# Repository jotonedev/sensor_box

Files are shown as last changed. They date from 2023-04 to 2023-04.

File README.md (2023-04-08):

# Sensor box v1

Final result

## Objective

Create a system capable of collecting environmental data and sending it to an MQTT broker by connecting to WiFi.

## Data to collect

- temperature (AHT20)
- humidity (AHT20)
- air quality (PMS7003, SGP30)
- atmospheric pressure (BMP180)

## Power supply

- 3.3V lithium battery
- solar panel

## Operation

Every 60 seconds, the system wakes up from a sleep state, checks the WiFi connection, collects and sends data to the
MQTT broker. During the interval of time between one transmission and the next, the system goes into a sleep state to
consume as little energy as possible.

## Topics MQTT

- `box01/temperature` (float, °C)
- `box01/humidity` (int, %)
- `box01/pressure` (int, Pa)
- `box01/caqi` (int)
- `box01/pm01` (int, ug/m3)
- `box01/pm25` (int, ug/m3)
- `box01/pm100` (int, ug/m3)
- `box01/eco2` (int, ppm)
- `box01/tvoc` (int, ppb)
- `box01/h2` (int, ppm)
- `box01/ethanol` (int, ppm)

## Circuit Diagram

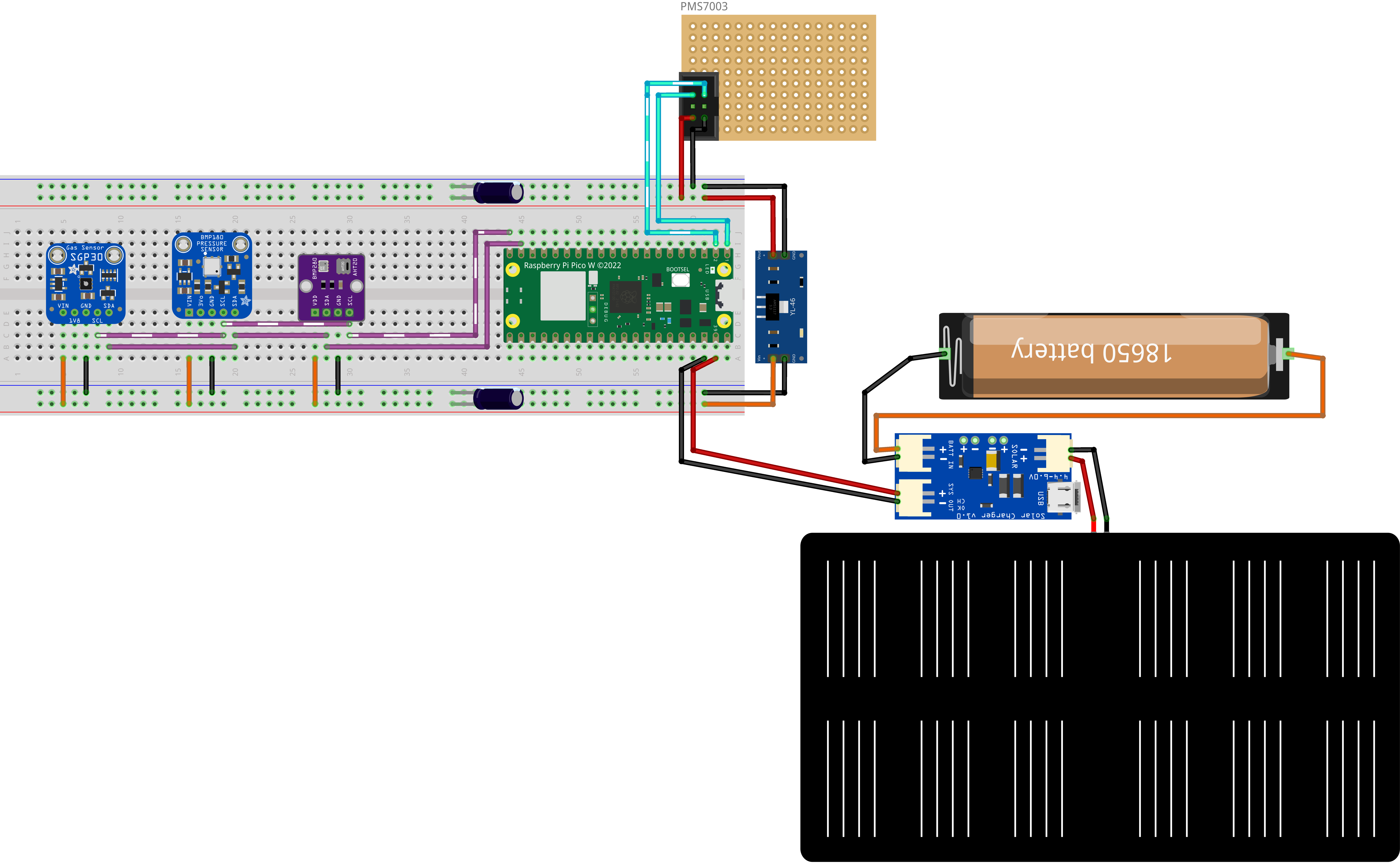
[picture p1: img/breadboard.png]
Breadboard view


## Hardware used

- Raspberry Pi Pico W (RP2040) or ESP32
- AHT20
- BMP180
- PMS7003
- SGP30
- Step-up converter 3.3 V - 5 V
- Solar panel
- CN3065
- 3.3V lithium battery

## License

[MIT License](LICENSE.md)

## Authors

- [John Toniutti](https://jotone.eu)

## Notes

- Currently, the DORMANT state isn't used because it doesn't work correctly.

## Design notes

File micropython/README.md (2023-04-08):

# Micropython version (prototype)

## Description

This was supposed to be the final version, but while testing I noticed that it consumed too much power and I was not able use lightsleep and deepsleep. 
So I redeveloped the project using the Arduino Framework.

## Programming language used

- [MicroPython](https://docs.micropython.org/en/latest/)

## Libraries used

- [SGP30](https://github.com/alexmrqt/micropython-sgp30)
- [PMS7003](https://github.com/pkucmus/micropython-pms7003)
- [MQTT](https://github.com/micropython/micropython-lib/blob/master/micropython/umqtt.simple/umqtt/simple.py)
- [BMP180](https://github.com/micropython-IMU/micropython-bmp180)
- [AHT20](https://github.com/targetblank/micropython_ahtx0)

## Notes

- Before using the code, you must change the Wi-Fi credentials and the MQTT broker address in the `conf.py` file.
- The code is not optimized for power consumption because _currently_ the lightsleep and deepsleep are broken in the
  MicroPython firmware for the Raspberry Pi Pico W. When the firmware is fixed, the code will be updated.

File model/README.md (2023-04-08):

# 3D models

## Description

This folder contains the 3D model of the sensor box in various file formats.
The measurement unit of the model is in millimeters.

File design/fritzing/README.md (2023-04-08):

# Fritzing schematics

## Description

This folder contains the Fritzing schematics of the sensor box.

## Download

You can download the Fritzing file from [here](https://fritzing.org/download/) or compile it
from [source](https://github.com/fritzing/fritzing-app).

## How to use

First of all, you should download the missing parts you can find below. \
Them, to view this project on Fritzing you should open the file [sensor_box.fz](sensor_box.fz).

## Missing parts

- [Raspberry Pi Pico W](https://datasheets.raspberrypi.com/picow/PicoW-Fritzing.fzpz),
  _[source](https://www.raspberrypi.com/documentation/microcontrollers/raspberry-pi-pico.html#pinout-and-design-files-2)_
- [Adafruit Bin](https://github.com/adafruit/Fritzing-Library/blob/master/AdaFruit.fzbz),
  _[source](https://github.com/adafruit/Fritzing-Library)_
- [AHT20+BMP280](https://forum.fritzing.org/uploads/short-url/cKIIjGdzIjD0t4vvrTt1Hf04cGl.fzpz),
  _[source](https://forum.fritzing.org/t/aht20-and-bmp280-breakout-board/17226)_
- [PMS7003](), _[source]()_
- [CN3065](https://forum.fritzing.org/uploads/short-url/qNhfAcX9Fwod1uYsVqazLqdnWAd.fzpz),
  _[source](https://forum.fritzing.org/t/solar-charge-module-5v/16492)_
- [Solar panel](made_parts/Solar%20panel%201.25W.fzpz),
  _[source](https://forum.fritzing.org/t/can-you-make-me-parts-from-these-illustrations/1983)_ and myself for doing the
  breadboard view
- [Battery holder](https://forum.fritzing.org/uploads/short-url/8MBpiFSpqxq8EDKTkda15LsPwfi.fzpz),
  _[source](https://forum.fritzing.org/t/18650-battery-holder-part-design/6523/20)_
- [Step-up converter](https://github.com/RafaGS/Fritzing/blob/master/DC-DC%20Power%20Module%20(3.3v)%20top.fzpz),
  _[source](https://github.com/RafaGS/Fritzing)_

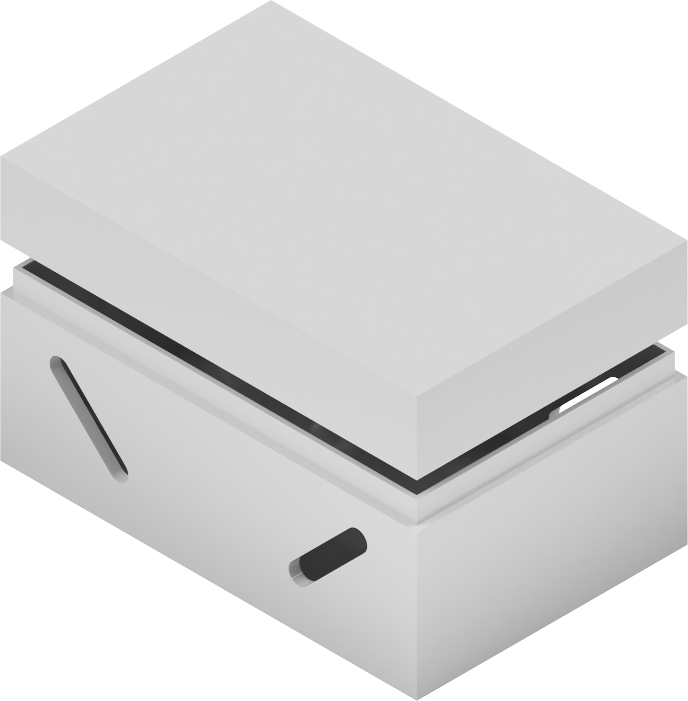
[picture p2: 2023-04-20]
img/model_render_01.png

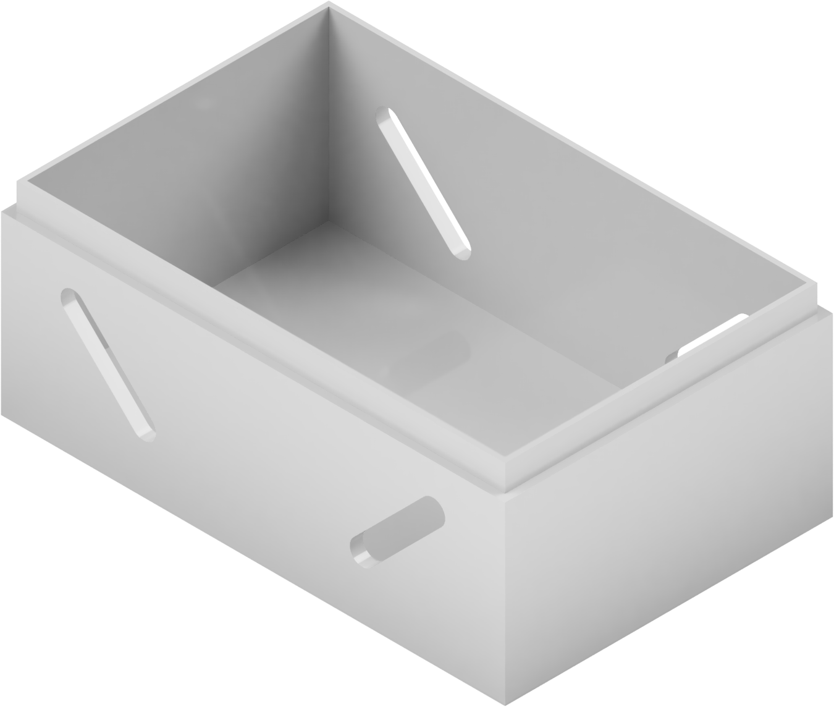
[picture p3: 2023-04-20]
img/model_render_02.png

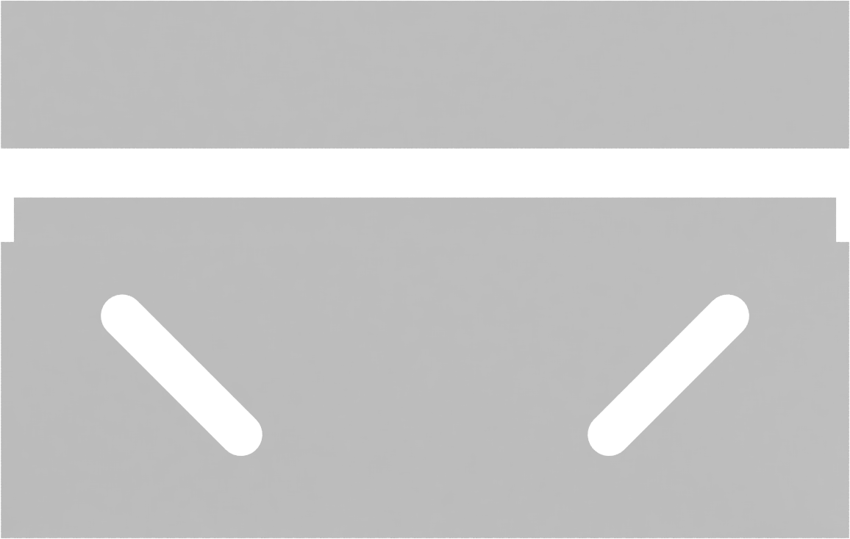
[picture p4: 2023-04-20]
img/model_render_03.png

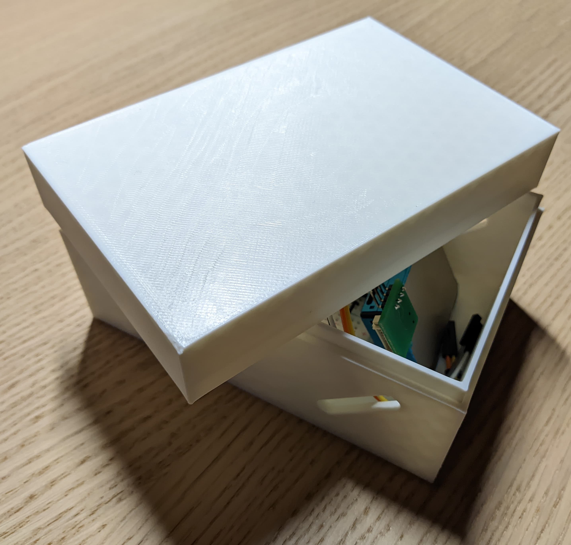
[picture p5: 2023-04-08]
img/model_real.jpg

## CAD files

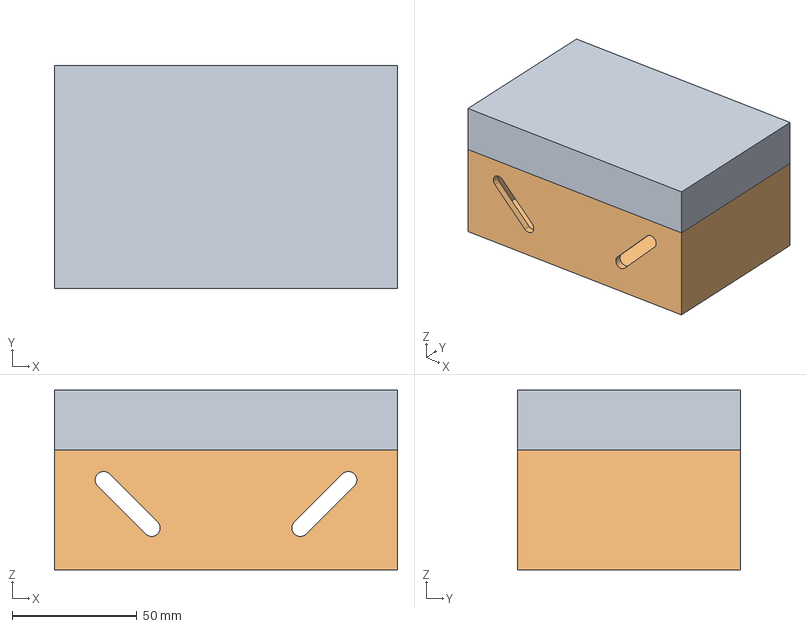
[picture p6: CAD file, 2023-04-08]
model/sensor_box.step
137.2 x 89.2 x 72.0 mm
Lid
Base

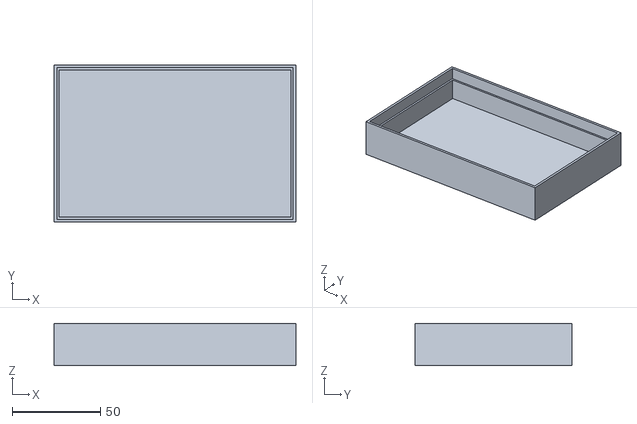
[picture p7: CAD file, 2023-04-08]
model/sensor_box_lid.stl
137.2 x 89.2 x 24.0

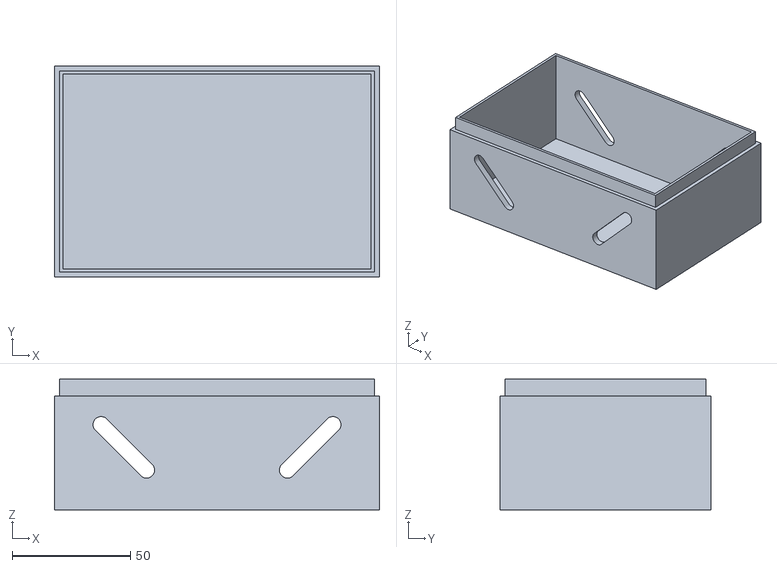
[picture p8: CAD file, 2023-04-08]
model/sensor_box_base.stl
137.2 x 89.2 x 55.2

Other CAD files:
model/sensor_box.3mf
model/sensor_box.f3d

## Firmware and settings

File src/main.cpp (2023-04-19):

#include <Arduino.h>
#include <WiFi.h>

#include <LittleFS.h>
#include <ArduinoMqttClient.h>
#include <PMS.h>
#include <Adafruit_I2CDevice.h>
#include <Adafruit_AHTX0.h>
#include <Adafruit_BMP085.h>
#include <Adafruit_SGP30.h>
#include <Wire.h>

#include "caqi.h"
#include "conf.h"
#include "utils.h"

#ifdef DEBUG
#define DEBUG_PRINT(x) Serial.println(x)
#else
#define DEBUG_PRINT(x)
#endif


// Forward declarations
void wifiConnect();
void pmsMeasure();
void ahtMeasure(TempData &temp_data);
void bmpMeasure(TempData &temp_data);
void sgpMeasure();
void sgpUpdateBaseline();
void sgpUpdateHumidity(TempData &temp_data);
inline void mqttPublish(const char *topic, int payload);
inline void mqttPublish(const char *topic, float payload, int precision);
inline void mqttPublish(const char *topic, const char *payload);


// Global objects
WiFiClient wifiClient;
MqttClient mqttClient(wifiClient);

PMS pms(Serial1);

Adafruit_AHTX0 aht20;
Adafruit_BMP085 bmp180;
Adafruit_SGP30 sgp30;


void setup() {
    // Init USB Serial
#ifdef DEBUG
    Serial.begin(115200);
    delay(3000);
#endif
    Serial1.begin(9600);

    // Init WiFi
#ifdef ARDUINO_RASPBERRY_PI_PICO_W
    WiFi.defaultLowPowerMode();
#endif
    if (WiFi.status() == WL_CONNECTED) {
        DEBUG_PRINT("Disconnecting previous connection");
        WiFi.disconnect();
    }
    wifiConnect();

    // Init MQTT
    DEBUG_PRINT("Connecting to MQTT broker");
    mqttClient.setId(CLIENT_ID);
    mqttClient.setKeepAliveInterval(320); // 5 minutes
    while (!mqttClient.connect(BROKER, BROKER_PORT)) {
        DEBUG_PRINT("Retrying...");
        delay(5000);
    }
    DEBUG_PRINT("Connected!");

    DEBUG_PRINT("Preparing sensors");

    // Init PMS
    pms.passiveMode();
    pms.sleep();

    // Init AHT20
    if (aht20.begin() != true) {  // aht20.begin() initialize and calibrate the sensor
        DEBUG_PRINT("AHT20 begin failed");
        mqttPublish(topic_err, "AHT20 begin failed");
        delay(5000);
    }

    // Init BMP180
    if (bmp180.begin(BMP085_ULTRALOWPOWER) != true) {  // By using ULTRALOWPOWER with reduce the samples to 3
        DEBUG_PRINT("BMP180 begin failed");
        mqttPublish(topic_err, "BMP180 begin failed");
        delay(5000);
    }

    // Init SGP30
    if (sgp30.begin() != true) {  // sgp30.begin() initialize and calibrate the sensor
        DEBUG_PRINT("SGP30 begin failed");
        mqttPublish(topic_err, "SGP30 begin failed");
        delay(5000);
    }
    // Read from flash baselines if available
    if (LittleFS.begin()) {
        File file = LittleFS.open("/baseline.txt", "r");
        if (file) {
            DEBUG_PRINT("Baseline file found");
            uint16_t eco2, tvoc;
            tvoc = file.parseInt();
            eco2 = file.parseInt();
            sgp30.setIAQBaseline(eco2, tvoc);
            file.close();
        } else {
            DEBUG_PRINT("Failed to open baseline.txt");
        }
        LittleFS.end();
    } else {
        DEBUG_PRINT("Failed to mount FS");
        mqttPublish(topic_err, "Failed to mount FS");
    }

    // Ready
    DEBUG_PRINT("Ready!");
    lightsleep(30); // 30 seconds
}


void loop() {
    TempData data;

    if (WiFi.status() != WL_CONNECTED)
        wifiConnect();
    mqttClient.poll();

    // Read PMS data
    pmsMeasure();

    // Read BMP180 data
    bmpMeasure(data);

    // Read AHT20 data
    ahtMeasure(data);

    // Read SGP30 data
    sgpMeasure();
    sgpUpdateHumidity(data);
    sgpUpdateBaseline();

    lightsleep(60 * 5); // 4 minutes
}


void pmsMeasure() {
    // Static variables used for caqi calculation
    static int pm_counter = 0;
    static int pm10_sum = 0;
    static int pm25_sum = 0;
    static unsigned long last_measure_time = millis();

    // struct to store PMS data
    PMS::DATA data;

    // Read PMS data
    while (Serial1.available()) { Serial1.read(); }  // Clear serial buffer
    pms.wakeUp();
    lightsleep(40); // 40 seconds
    pms.requestRead(); Serial1.flush();
    if (!pms.readUntil(data, 5000)) {
        DEBUG_PRINT("PMS read failed");
        mqttPublish(topic_err, "PMS read failed");
        pms.sleep(); Serial1.flush();
        return;
    }
    pms.sleep(); Serial1.flush();

    // Increase counter for caqi calculation
    pm_counter++;
    pm10_sum += data.PM_AE_UG_10_0;
    pm25_sum += data.PM_AE_UG_2_5;

    // Check if it's time to calculate caqi and send data to MQTT broker
    if (millis() <= last_measure_time || millis() - last_measure_time >= 3600000) {  // measure every hour
        // Calculate CAQI
        int caqi = calculate_caqi(pm25_sum / pm_counter, pm10_sum / pm_counter);
        // Reset pm values
        last_measure_time = millis();
        pm_counter = 0;
        pm10_sum = 0;
        pm25_sum = 0;
        // Send CAQI to MQTT broker
        mqttPublish(topic_caqi, caqi);
    }

    // Send PMS data to MQTT broker
    mqttPublish(topic_pm01, data.PM_AE_UG_1_0);
    mqttPublish(topic_pm25, data.PM_AE_UG_2_5);
    mqttPublish(topic_pm100, data.PM_AE_UG_10_0);
}


void ahtMeasure(TempData &temp_data) {
    sensors_event_t temp, hum;
    if (!aht20.getEvent(&hum, &temp)) {
        DEBUG_PRINT("AHT20 getEvent failed");
        mqttPublish(topic_err, "AHT20 getEvent failed");
        return;
    };

    if (temp_data.temperature != 0) {
        // Average temperature with value from bmp180
        temp_data.temperature = (temp.temperature + temp_data.temperature) / 2;
    } else {
        temp_data.temperature = temp.temperature;
    }
    temp_data.humidity = hum.relative_humidity;

    // Send AHT20 data to MQTT broker
    mqttPublish(topic_temp, temp_data.temperature, 1);
    mqttPublish(topic_hum, temp_data.humidity, 0);
}


void bmpMeasure(TempData &temp_data) {
    int pressure = bmp180.readPressure();
    temp_data.temperature = bmp180.readTemperature();

    pressure = pressure - (pressure % 10);  // Round to nearest 10
    // Send BMP180 data to MQTT broker
    mqttPublish(topic_pres, pressure);
}


void sgpMeasure() {
    if (sgp30.IAQmeasureRaw()) {
        delay(50); // Wait for measurement to complete
        if (sgp30.IAQmeasure()) {
            mqttPublish(topic_tvoc, sgp30.TVOC);
            mqttPublish(topic_eco2, sgp30.eCO2);
        } else {
            DEBUG_PRINT("SGP30 IAQmeasure failed");
            mqttPublish(topic_err, "SGP30 IAQmeasure failed");
        }

        mqttPublish(topic_h2, sgp30.rawH2);
        mqttPublish(topic_ethanol, sgp30.rawEthanol);
    } else {
        DEBUG_PRINT("SGP30 IAQmeasureRaw failed");
        mqttPublish(topic_err, "SGP30 IAQmeasureRaw failed");
    }
}


void sgpUpdateBaseline() {
    static long next_baseline_update = 43200000;

    // Wait for 12 hours before saving the first baseline
    if (millis() <= next_baseline_update) {
        return;
    } else {
        // After the first baseline is saved, update it every hour
        next_baseline_update = millis() + 3600000;
    }

    // Read baseline from SGP30
    uint16_t eco2, tvoc;
    if (sgp30.getIAQBaseline(&eco2, &tvoc)) {
        // Write baseline to flash
        LittleFS.begin();
        File file = LittleFS.open("/baseline.txt", "w");
        if (file) {
            file.println(tvoc);
            file.println(eco2);
            file.close();
            DEBUG_PRINT("Baseline written to flash");
        } else {
            DEBUG_PRINT("Failed to write, baseline.txt");
            mqttPublish(topic_err, "Failed to write, baseline.txt");
        }
        LittleFS.end();
    }
}


void sgpUpdateHumidity(TempData &temp_data) {
    static long next_humidity_update = 0;

    // Update humidity every 6 hours
    if (millis() <= next_humidity_update) {
        return;
    } else {
        next_humidity_update = millis() + 21600000;
    }

    // Set abosulute humidity
    sgp30.setHumidity(getAbsoluteHumidity(temp_data.temperature, temp_data.humidity));
}


inline void mqttPublish(const char *topic, int payload) {
    if (!mqttClient.beginMessage(topic)) {
        DEBUG_PRINT("MQTT begin message failed");
        return;
    }

    #ifdef DEBUG
        Serial.print(topic);
        Serial.print(": ");
        Serial.println(payload);
    #endif
    mqttClient.print(payload);

    if (!mqttClient.endMessage())
        DEBUG_PRINT("MQTT end message failed");
}


inline void mqttPublish(const char *topic, float payload, int precision) {
    if (!mqttClient.beginMessage(topic)) {
        DEBUG_PRINT("MQTT begin message failed");
        return;
    }
    
    #ifdef DEBUG
        Serial.print(topic);
        Serial.print(": ");
        Serial.println(payload, precision);
    #endif
    
    mqttClient.print(payload, precision);

    if (!mqttClient.endMessage())
        DEBUG_PRINT("MQTT end message failed");
}


inline void mqttPublish(const char *topic, const char *payload) {
    if (!mqttClient.beginMessage(topic, false, 1, false)) {
        DEBUG_PRINT("MQTT begin message failed");
        return;
    }

    #ifdef DEBUG
        Serial.print(topic);
        Serial.print(": ");
        Serial.println(payload);
    #endif
    mqttClient.print(payload);

    if (!mqttClient.endMessage())
        DEBUG_PRINT("MQTT end message failed");
}


void wifiConnect() {
    DEBUG_PRINT("Connecting to WiFi");
    while (WiFi.begin(SSID, PASS) != WL_CONNECTED) {
        DEBUG_PRINT("Retrying...");
        delay(5000);
        WiFi.disconnect();
    }
    DEBUG_PRINT("Connected!");
}

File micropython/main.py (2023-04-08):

import gc

import machine
import micropython
import network
import rp2
from machine import Pin, I2C, UART
from utime import time, sleep_ms, sleep

from aht20 import AHT20
from bmp180 import BMP180, BMP180_ULTRALOWPOWER
from caqi import CAQI
from conf import WIFI_COUNTRY, WIFI_SSID, WIFI_BSID, WIFI_PASS, MQTT_NAME, MQTT_HOST, MQTT_PORT
from mqtt import MQTTClient
from pms import PMS
from sgp30 import SGP30

# WiFI settings
rp2.country(WIFI_COUNTRY)

# Global variables
client = MQTTClient(MQTT_NAME, MQTT_HOST, keepalive=60, port=MQTT_PORT)
wlan: network.WLAN = None
wlan_pw = machine.Pin(23, Pin.OUT)

# I2C bus
i2c1 = I2C(1, scl=Pin(15), sda=Pin(14))

# Temperature and humidity sensor
aht20: AHT20 = AHT20(i2c1)

# Pressure sensor
bmp180: BMP180 = BMP180(i2c1, mode=BMP180_ULTRALOWPOWER)

# Air quality sensor
sgp30: SGP30 = SGP30(i2c1)
baseline_time: int = 0

# Particle sensor
uart = UART(0)
pms: PMS = PMS(uart)
pm25_sum: int = 0
pm100_sum: int = 0
pm_values: int = 0
caqi_time: int = time()


# noinspection PyBroadException
@micropython.native
def lightsleep(seconds: int):
    for _ in range(seconds * 1_000):
        machine.lightsleep(1)


def wifi_connect() -> bool:
    global wlan_pw, wlan

    if wlan_pw.value() == 0:
        wlan_pw.high()
        sleep_ms(500)

    if wlan is None:
        wlan = network.WLAN(network.STA_IF)
        wlan.active(True)

    if not wlan.isconnected():
        wlan.connect(WIFI_SSID, WIFI_PASS, bssid=WIFI_BSID)
        print("Connecting to WiFi")

        # timeout for connection
        timeout = time() + 30
        while not wlan.isconnected():
            sleep_ms(50)
            if time() > timeout:
                print("WiFi timeout connection")
                return False

        print("Connected to Wifi")
        print("IP: " + wlan.ifconfig()[0])

    return True


def setup():
    global baseline_time

    # Reduce clock
    machine.freq(64_000_000)

    # Enable garbage collection
    gc.enable()

    # AHT20
    aht20.reset()
    if not aht20.calibrate():
        print("Could not calibrate AHT20")
        machine.deepsleep(60_000)

    # BMP180
    bmp180.initialize()

    # SGP30
    sgp30.iaq_init()
    try:
        f_co2 = open("co2eq_baseline.txt", 'r')
        f_tvoc = open("tvoc_baseline.txt", 'r')

        co2_baseline = int(f_co2.read())
        tvoc_baseline = int(f_tvoc.read())
    except (ValueError, OSError):
        print("Impossible to read SGP30 baselines!")
    else:
        print("Baselines loaded")
        sgp30.set_iaq_baseline(co2_baseline, tvoc_baseline)
        f_co2.close()
        f_tvoc.close()
    finally:
        baseline_time = time()

    # PMS7003
    pms.pas_mode()

    # Setup MQTT
    client.connect(clean_session=True)


def run():
    global baseline_time
    global pm25_sum, pm100_sum, caqi_time, pm_values

    # measure aht20 (temperature and humidity)
    aht20.read()
    temp = aht20.temperature
    hum = aht20.relative_humidity
    client.publish("box01/temperature", str(round(temp, 1)))
    client.publish("box01/humidity", str(round(hum, 0)))

    # measure bmp280 (pressure)
    pres = bmp180.pressure
    pres = int(round(pres / 10) * 10)
    client.publish("box01/pressure", str(pres))

    # measure sgp30 (co2 and tvoc)
    co2_eq, tvoc = sgp30.iaq_measure()
    client.publish("box01/eco2", str(co2_eq))
    client.publish("box01/tvoc", str(tvoc))

    if time() - baseline_time >= 3600:
        try:
            f_co2 = open("co2eq_baseline.txt", 'w')
            f_tvoc = open("tvoc_baseline.txt", 'w')

            bl_co2, bl_tvoc = sgp30.get_iaq_baseline()
            f_co2.write(str(bl_co2))
            f_tvoc.write(str(bl_tvoc))

            sgp30.set_iaq_rel_humidity(temp=temp, rh=hum)

            f_co2.close()
            f_tvoc.close()
        except OSError:
            print("Impossible to save SGP30 baselines!")
        finally:
            print("Baselines saved")
            baseline_time = time()

    # measure pms7003 (pm10, pm25, pm100)
    pms.wake_up()
    lightsleep(30)
    pms.prepare_read()
    pms_data = pms.read()
    pms.sleep()

    pm10 = pms_data[4]
    pm25 = pms_data[5]
    pm100 = pms_data[6]
    pm25_sum += pm25
    pm100_sum += pm100
    pm_values += 1

    if time() - caqi_time >= 3600:
        pm100_avg = pm100_sum // pm_values
        pm25_avg = pm25_sum // pm_values
        caqi = CAQI.caqi(pm25_avg, pm100_avg)
        client.publish("box01/caqi", str(caqi))
        pm25_sum = 0
        pm100_sum = 0
        pm_values = 0
        caqi_time = time()

    client.publish("box01/pm01", str(pm10))
    client.publish("box01/pm25", str(pm25))
    client.publish("box01/pm100", str(pm100))


try:
    print("Running setup")
    wifi_connect()
    setup()
    print("Setup complete")
except Exception as e:
    print(str(e))
    sleep_ms(50)
    machine.deepsleep(60_000)
else:
    lightsleep(30)  # wait for sensors to settle

while True:
    try:
        print("Waking up")
        wifi_connect()
        client.connect()

        print("Running main loop")
        run()

        print("Going sleep")
        client.disconnect()
        gc.collect()
    except Exception as e:
        print(str(e))
        sleep_ms(50)
        machine.deepsleep(60_000)
    else:
        sleep_ms(50)
        lightsleep(300)  # sleep for 5 minute
